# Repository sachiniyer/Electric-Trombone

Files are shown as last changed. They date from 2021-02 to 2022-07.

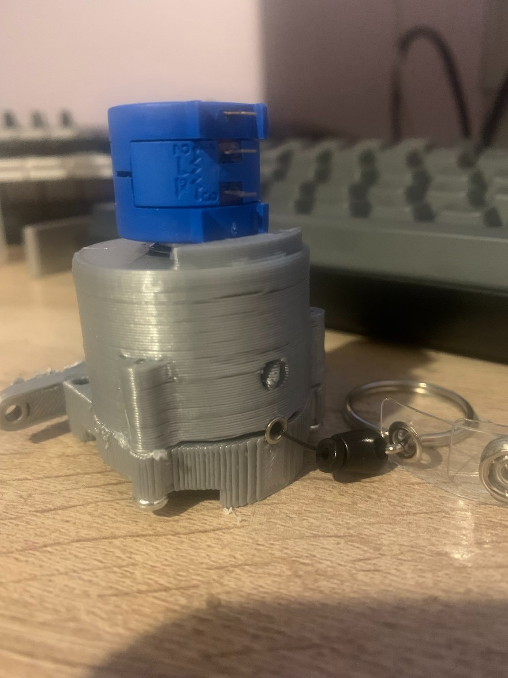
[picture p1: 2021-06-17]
v4/models/string_pot.jpeg

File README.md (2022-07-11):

# Electronic Trombone
This is an attempt to make an electronic trombone. Currently, I am on the fourth iteration. I am not sure when I will create a physical model (hopeully sometime in august if I can make some time in the NYU Makerspace). I haven't done an update in about a year, but I hoping to get something working finally.

## Code
It is very easy, and uses buttons to change partials. Depending on the iteration, either a rotational potentiometer or time of flight sensor is used for distance. A pressure sensor captures breath changes.

## Iteration 1
This was a proof of concept where I used a time of flight sensor to read the distance levels of the slide in an attempt to keep slide movement free. However, it was not accurate enough (it was fast however). Videos under "./v1/E-bone".

## Iteration 2
This was a fully mechanical solution where I used 3D printed parts to create a gearing mechanism with a constant force spring and rotational potentiometer. However, it broke as it was under too much tension. Models under "./v2/E-bone2".

## Iteration 3
Now, I am trying to build a different gearbox with partially 3D printed parts and metal parts. This is also following a different design which should put less strain on the parts. Models under "./v3/E-bone3"
Update June 12, 2021: This did not work as planned, it was too complicated, and did not end up being a viable solution. This was ultimately due to not using mechanical advantage. Instead there was undue stress on many of the pieces and the build ended up failing.

## Iteration 4
I am hoping this is the first actual working iteration of the electronic trombone, and around the model that I will end up sticking with. This time I have a direct connection from the string to constant force spring. It is also a much more compact solution, and one that I think will actually be able to work in my favor instead of a hodgepodge of random elements thrown together. This iteration is a lot more robust and simplistic than the previous couple.

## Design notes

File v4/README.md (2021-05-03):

# Big Realization
I was trying to make the constant force spring with a bunch of 3d printed parts, a lot of which were failing. I however realized that I could just use a 3 foot badge reel connected to a rotational potentiometer to create a much simpler string pot.

This is instead going to be the new model for detecting linear distance, one that I should have done at the start of the project. I would also have bought a string potentiometer, which would have been a much more plug and play solution, but for some reason, they cost like $200.

I was inspired to do this when I saw a string pot in the nyu robotics lab and was just absolutely dumbfounded at how amazing it looked.

# STL files
These are unabashedly taken from https://www.thingiverse.com/thing:1926226. This seems to be taken from andymark, which is where I'm getting the badge reel and some hardware.

The ten turn pot is https://www.digikey.com/en/products/detail/bourns-inc/3590S-2-103L/1088586.

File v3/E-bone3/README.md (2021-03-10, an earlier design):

# Main Changes

## Frictional Issues
This version takes a lot from the last version, but instead aims to distribute force a lot more effectively. Last attempt was not force efficient at all resulting in a lot of unnecessary friction. The main source of this friction was due to the 90 degree angle between the gearing mechanism and the slide, which made it very difficult to pull. This version instead mounts everything at the end of the slide which means that it should be interacting at a 180 degree angle allowing the string to interface directly and transfer more of the force to the constant force spring. The major downfall of this may be that it is harder to hold with a lot of the weight at the end of slide (this is what I was trying to avoid initially). To solve this problem, I've cut down on the amount of moving parts by as much as possible.

## Shearing Issues
The second model was built with the main shaft standing tall on the build plate. This meant that rotational force on the shaft cause the print layers to split more often than they needed to. This build I'm making a conscious decision to build the main shaft horizontally, along with more chamfers in high torque areas to distribute the force more evenly.

## Constant Force Spring Issues
The amount of measurements and calculations I had done when selecting the constant force spring and building the mount were very rudimentary at the start. I was not taking advantage of the full length of the spring and passing on too little force to the slide. This time, I intentionally created a difference in radius between the portion of shaft that interfaces with the string connected to the slide and the portion of the shaft that interfaces with the spring. This was calculated to use the whole spring over the course of the slide length. It should deliver more force and be more stable due to increased strength hopefully.

## Mounting Electronics
This time, I am making better mounting hardware. I am also aiming to use as little duct tape in this version as possible (the last two were full of it).

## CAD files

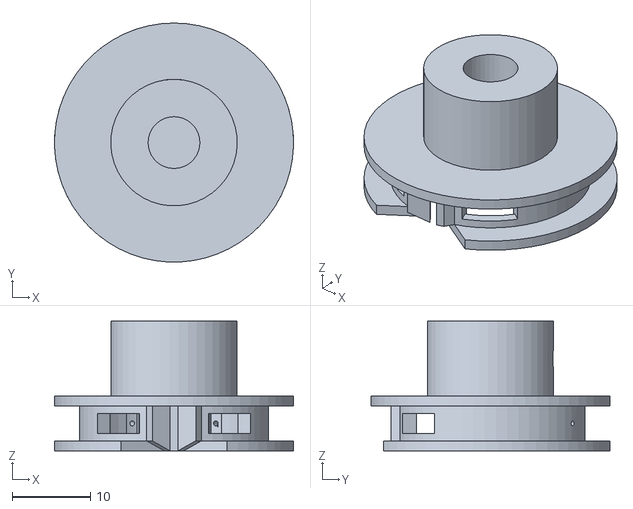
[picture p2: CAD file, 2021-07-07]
v4/models/inner.stl
30.5 x 30.5 x 16.5

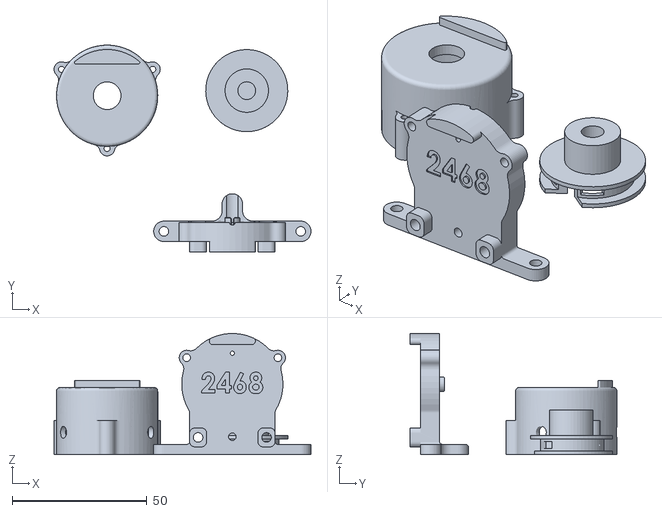
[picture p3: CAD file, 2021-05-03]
v4/models/string_pot.stl
95.4 x 76.8 x 45.0

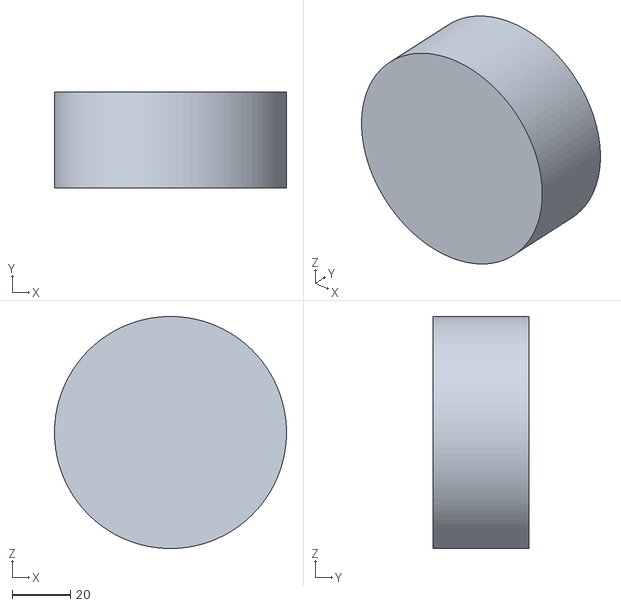
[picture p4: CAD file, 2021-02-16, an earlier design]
v2/E-bone2/Models/models/new gear assembly v1.stl
80.0 x 33.0 x 80.0

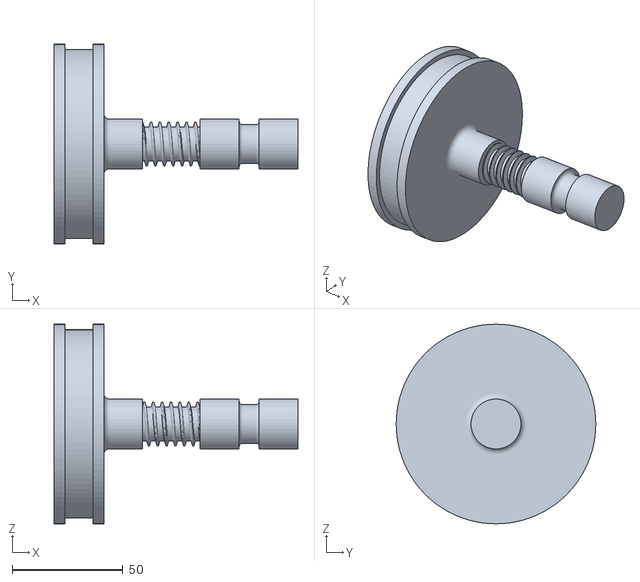
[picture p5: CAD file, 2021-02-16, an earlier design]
v3/E-bone3/model/main.stl
110.0 x 90.0 x 90.0

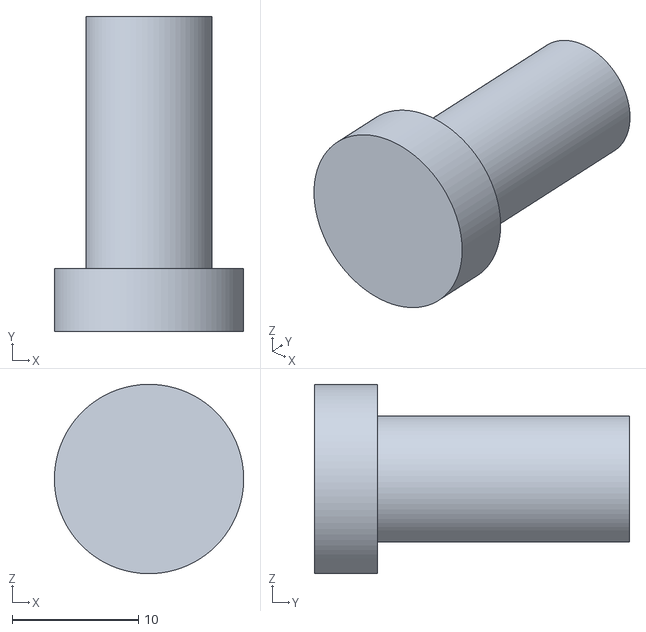
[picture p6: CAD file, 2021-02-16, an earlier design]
v2/E-bone2/Models/models/gear assembly v1.stl
15.0 x 25.0 x 15.0

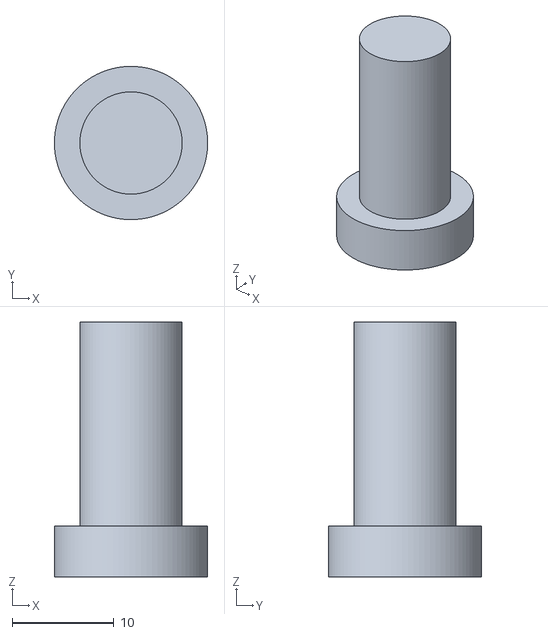
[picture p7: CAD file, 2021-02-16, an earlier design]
v2/E-bone2/Models/models/gear assembly 2.stl
15.0 x 15.0 x 25.0

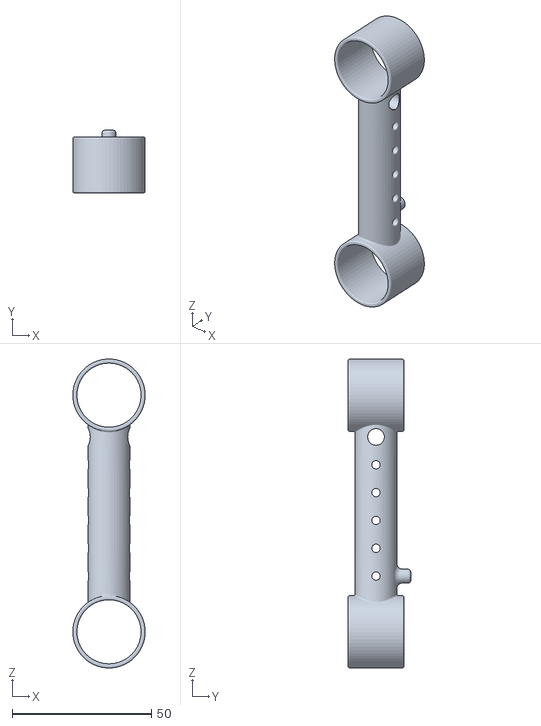
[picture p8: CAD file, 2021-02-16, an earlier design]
v2/E-bone2/Models/Electric Trombone Hand Piece v1.stl
26.0 x 22.5 x 111.0

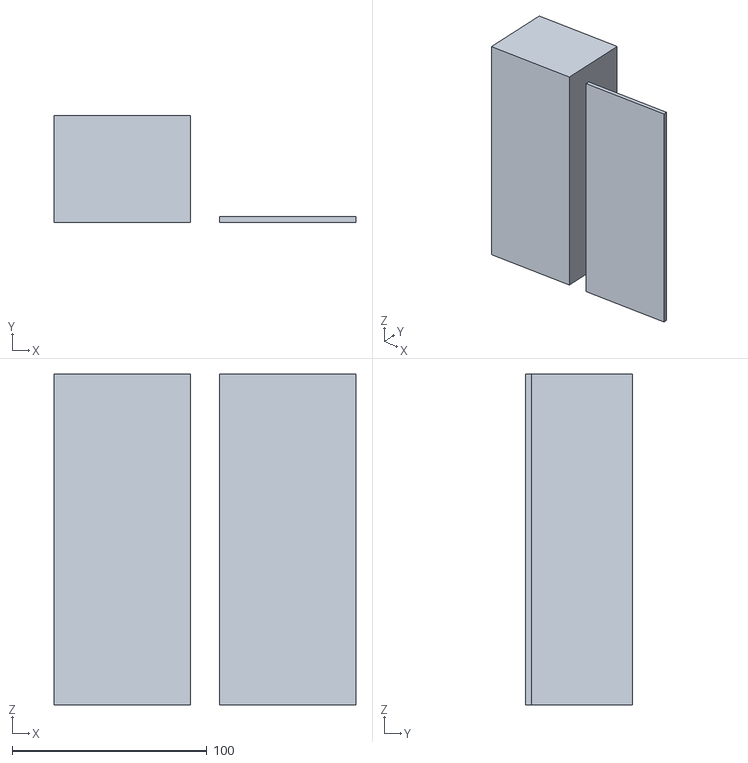
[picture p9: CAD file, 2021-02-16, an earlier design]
v2/E-bone2/Models/models/yatin gift.stl
155.0 x 55.0 x 170.0

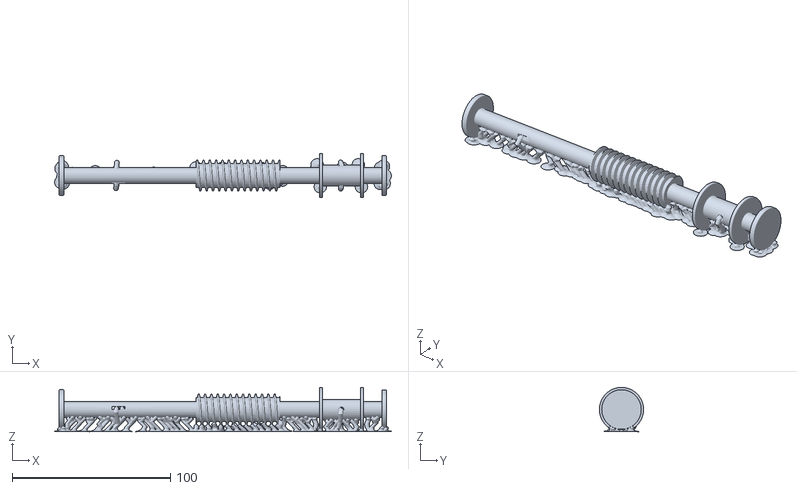
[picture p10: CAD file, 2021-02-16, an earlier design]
v2/E-bone2/processed/stl/shaft.stl
213.1 x 28.0 x 28.0

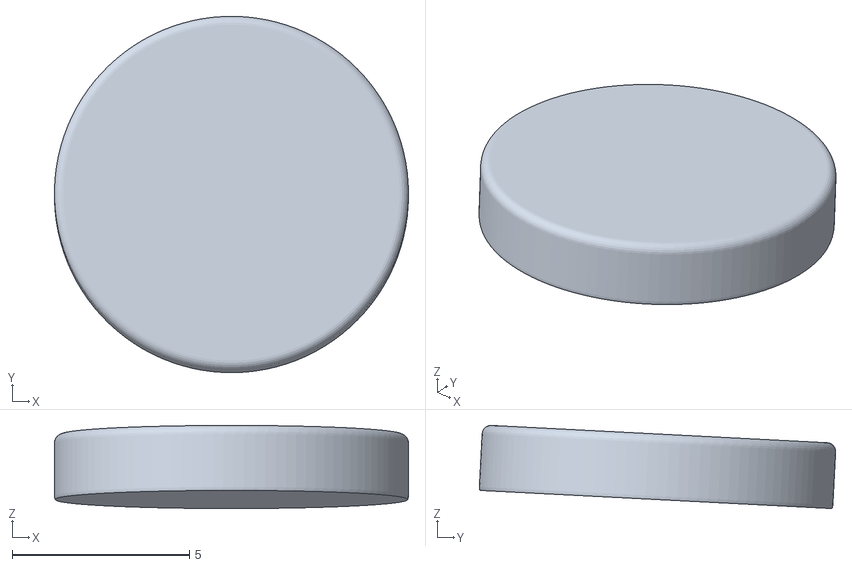
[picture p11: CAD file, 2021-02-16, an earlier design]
v2/E-bone2/processed/stl_hollow/gear 2.stl
10.00 x 10.1 x 2.35

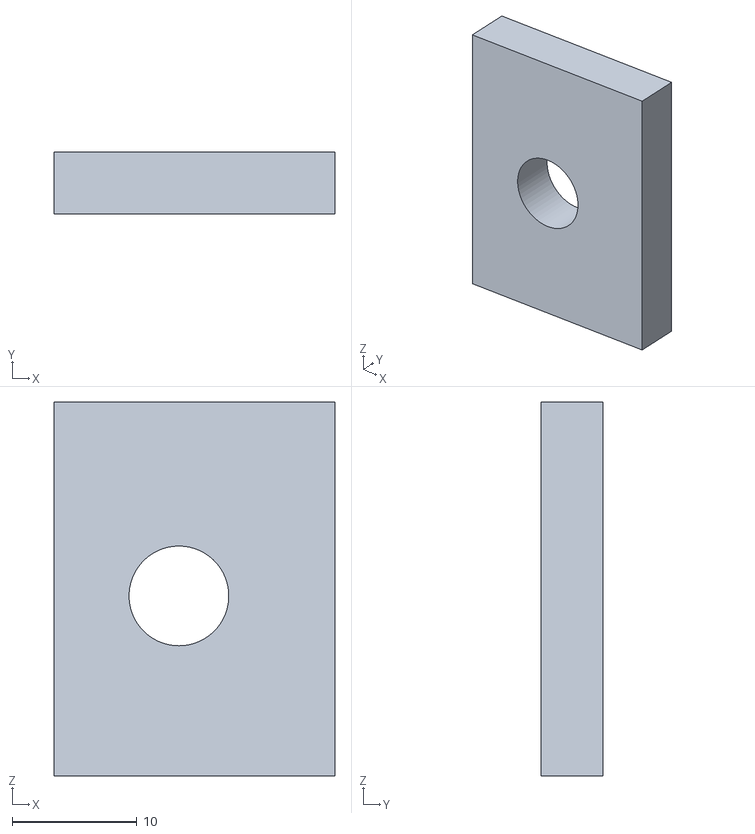
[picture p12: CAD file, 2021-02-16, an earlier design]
v3/E-bone3/model/gear holder 2.stl
22.5 x 5.00 x 30.0

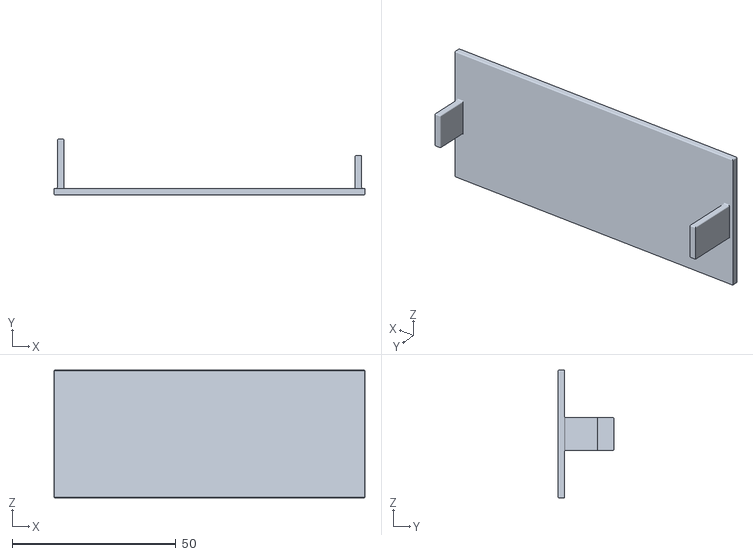
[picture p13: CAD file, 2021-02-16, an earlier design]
v2/E-bone2/models/cover.stl
95.0 x 17.0 x 39.0

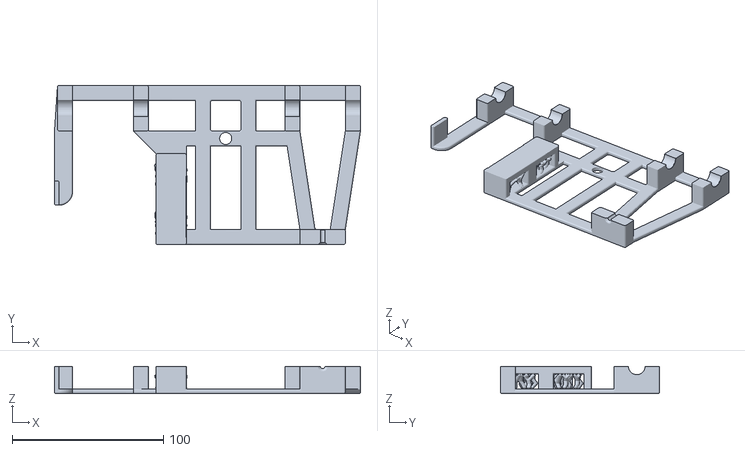
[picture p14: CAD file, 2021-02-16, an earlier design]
v2/E-bone2/processed/stl/body 1.stl
202.0 x 105.0 x 18.0

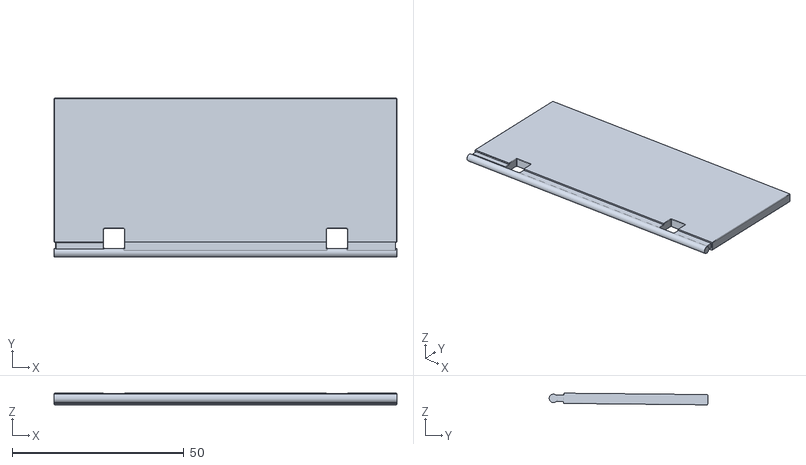
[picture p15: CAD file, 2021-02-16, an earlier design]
v2/E-bone2/processed/stl_hollow/cap.stl
100.0 x 46.3 x 3.42

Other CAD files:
v3/E-bone3/model/gear.stl
v2/E-bone2/Models/models/spring.stl
v2/E-bone2/models/shaft.stl
v2/E-bone2/processed/stl/cover.stl
v2/E-bone2/Models/Electric Trombone Hand Piece v1.f3d
v2/E-bone2/Models/models/gearupdated1.stl
v2/E-bone2/Models/models/gearupdatedhollow.stl
v2/E-bone2/Models/models/hand_piece_hollow.stl
v2/E-bone2/Models/models/mouthpieceblendermesh.stl
v2/E-bone2/Models/models/mouthpieceblendermesh2.stl
v2/E-bone2/Models/models/small yatin gift.stl
v2/E-bone2/Models/models/spring v1.stl
v2/E-bone2/Models/mouthpiece.stl
v2/E-bone2/Models/mouthpieceblender1.stl
v2/E-bone2/models/body 1.stl
v2/E-bone2/models/body 2.stl
v2/E-bone2/models/body 3:4.stl
v2/E-bone2/models/cap.stl
v2/E-bone2/models/gear 1.stl
v2/E-bone2/models/gear 2.stl
v2/E-bone2/processed/stl/cap.stl
v2/E-bone2/processed/stl/gear 1.stl
v2/E-bone2/processed/stl_hollow/body 3:4.stl
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

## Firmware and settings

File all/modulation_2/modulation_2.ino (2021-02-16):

/*
 * MIDIUSB_test.ino
 *
 * Created: 4/6/2015 10:47:08 AM
 * Author: gurbrinder grewal
 * Modified by Arduino LLC (2015)
 */

#include "MIDIUSB.h"

// First parameter is the event type (0x09 = note on, 0x08 = note off).
// Second parameter is note-on/note-off, combined with the channel.
// Channel can be anything between 0-15. Typically reported to the user as 1-16.
// Third parameter is the note number (48 = middle C).
// Fourth parameter is the velocity (64 = normal, 127 = fastest).

void noteOn(byte channel, byte pitch, byte velocity) {
  midiEventPacket_t noteOn = {0x09, 0x90 | channel, pitch, velocity};
  MidiUSB.sendMIDI(noteOn);
}

void noteOff(byte channel, byte pitch, byte velocity) {
  midiEventPacket_t noteOff = {0x08, 0x80 | channel, pitch, velocity};
  MidiUSB.sendMIDI(noteOff);
}

void setup() {
  Serial.begin(115200);
}

// First parameter is the event type (0x0B = control change).
// Second parameter is the event type, combined with the channel.
// Third parameter is the control number number (0-119).
// Fourth parameter is the control value (0-127).

void controlChange(byte channel, byte control, byte value) {
  midiEventPacket_t event = {0x0B, 0xB0 | channel, control, value};
  MidiUSB.sendMIDI(event);
}

void loop() {
    int val;
  val = random(20,100);
    noteOn(1, val, 64);
    MidiUSB.flush();
    delay(100);
    noteOff(1, val, 64);
    MidiUSB.flush();
   delay(100);
  controlChange(0, 10, 65); // Set the value of controller 10 on channel 0 to 65
}

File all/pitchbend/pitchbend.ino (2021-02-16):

/*
  MIDI pitch bend example
  plays a noteOn every two seconds, then uses a potentiometer
  to bend the pitch
  Uses MIDIUSB for MIDI, so will work on any
  32U4-based board (e.g. Uno, Leonardo, Micro, Yún)
  Circuit:
      potentiometer connected to pin 10
  created 17 Feb 2019
  by Tom Igoe
*/

#include <MIDIUSB.h>      // include MIDIUSB library
#include <pitchToNote.h>  // include pitch chart from MIDIUSB library

void setup() {
  Serial.begin(115200);                  // initialize serial
}

void loop() {
  // play a note every two seconds:
  if (millis() % 2000 < 2) {
    midiCommand(0x80, pitchC4, 0);
    midiCommand(0x90, pitchC4, 64);
  }

  int sensor = analogRead(10);
  // pitch bend range is 0 - 16383, and
  // the middle of the range, 8192, is zero pitch bend:

  int pitchBend = map(sensor, 0, 1023, 0, 16383);
  Serial.print(pitchBend);

  // convert 8-bit bytes to 7-bit bytes:
  pitchBend = pitchBend << 1;          // shift low byte's msb to high byte
  byte msb = highByte(pitchBend);      // get the high bits
  byte lsb = lowByte(pitchBend) >> 1;  // get the low 8 bits

// print the values, for reference:

  Serial.print(" ");
  Serial.print(msb);
  Serial.print(" ");
  Serial.println(lsb);


  // send the pitch bend message:
  midiCommand(0xE0, lsb, msb);
}

void midiCommand(byte cmd, byte data1, byte  data2) {
  // First parameter is the event type (top 4 bits of the command byte).
  // Second parameter is command byte combined with the channel.
  // Third parameter is the first data byte
  // Fourth parameter second data byte

  midiEventPacket_t midiMsg = {cmd >> 4, cmd, data1, data2};
  MidiUSB.sendMIDI(midiMsg);
}

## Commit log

2021-02-16 stages 2 and 3 to make public
    [Electric Trombone Hand Piece v1.f3d, Electric Trombone Hand Piece v1.stl, Gear holder.stl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]
2021-05-03 add 4th revision stls
    [string_pot.stl]
2021-06-17 remove gcode
    [body 3:4.stl, cap.stl, cover.stl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]
2021-07-07 add models to v4 and remove create more organization
    [inner.stl, string_pot.stl]
